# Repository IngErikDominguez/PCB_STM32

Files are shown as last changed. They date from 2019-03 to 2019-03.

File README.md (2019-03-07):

# PCB_STM32
PCB_STM32 

El PCB de Stm32 se comienza con el objetivo de sustituir el arduino nano, por un desarrollo generado aquí. El objetivo del microcontrolador, será embeber la comunicación serial con los dispositivos ccTalk, monitorear sensores que se empiecen a implementar, como lo son: sensor de corriente, voltaje, temperatura y tener una comunicación mas transparente con un software de PC o Raspberry por comunicación serial

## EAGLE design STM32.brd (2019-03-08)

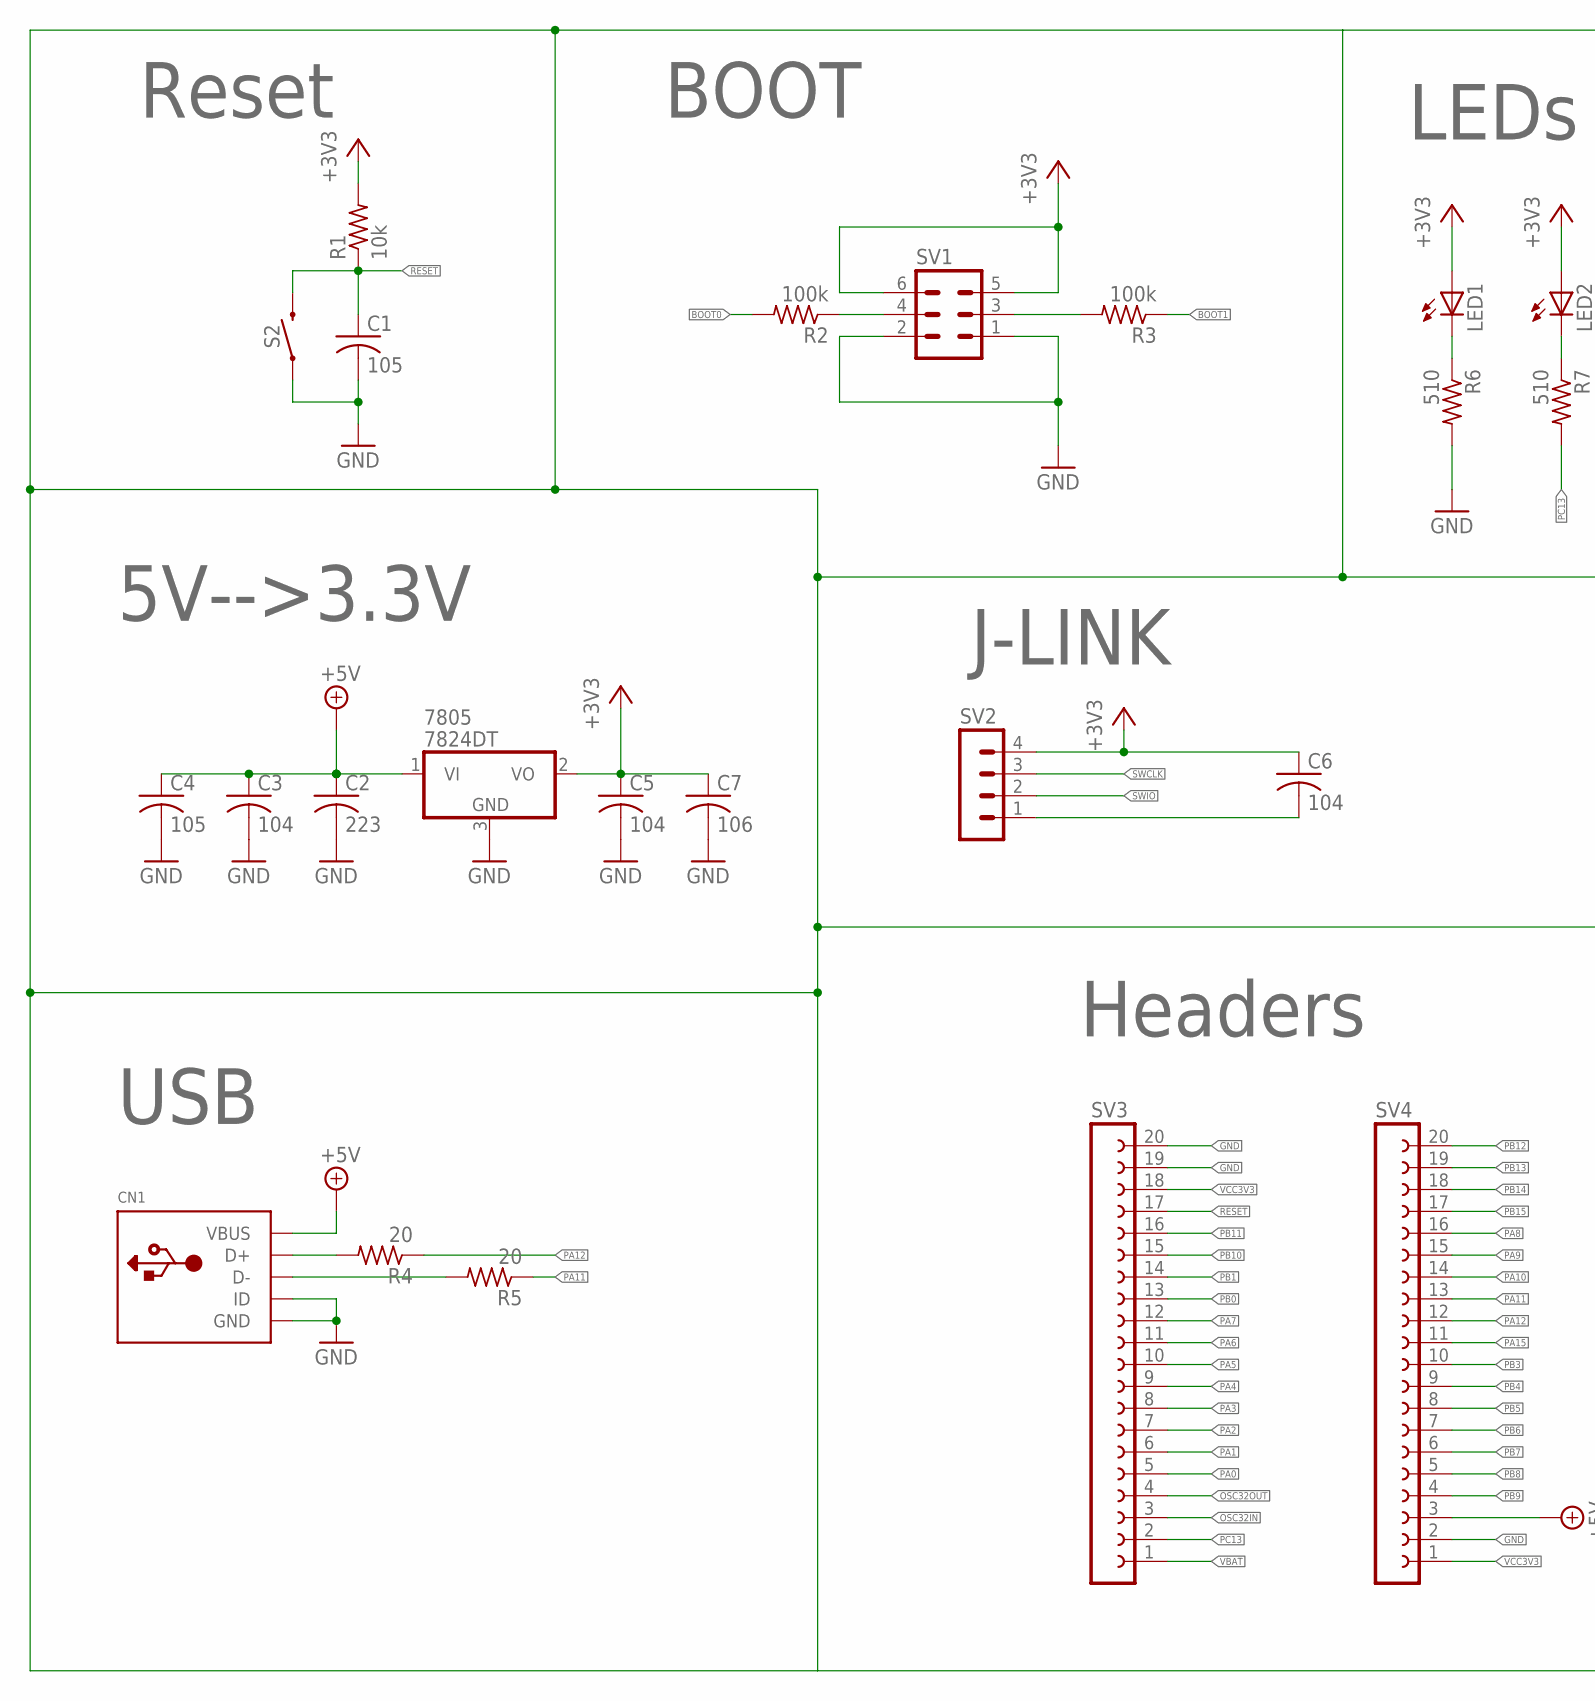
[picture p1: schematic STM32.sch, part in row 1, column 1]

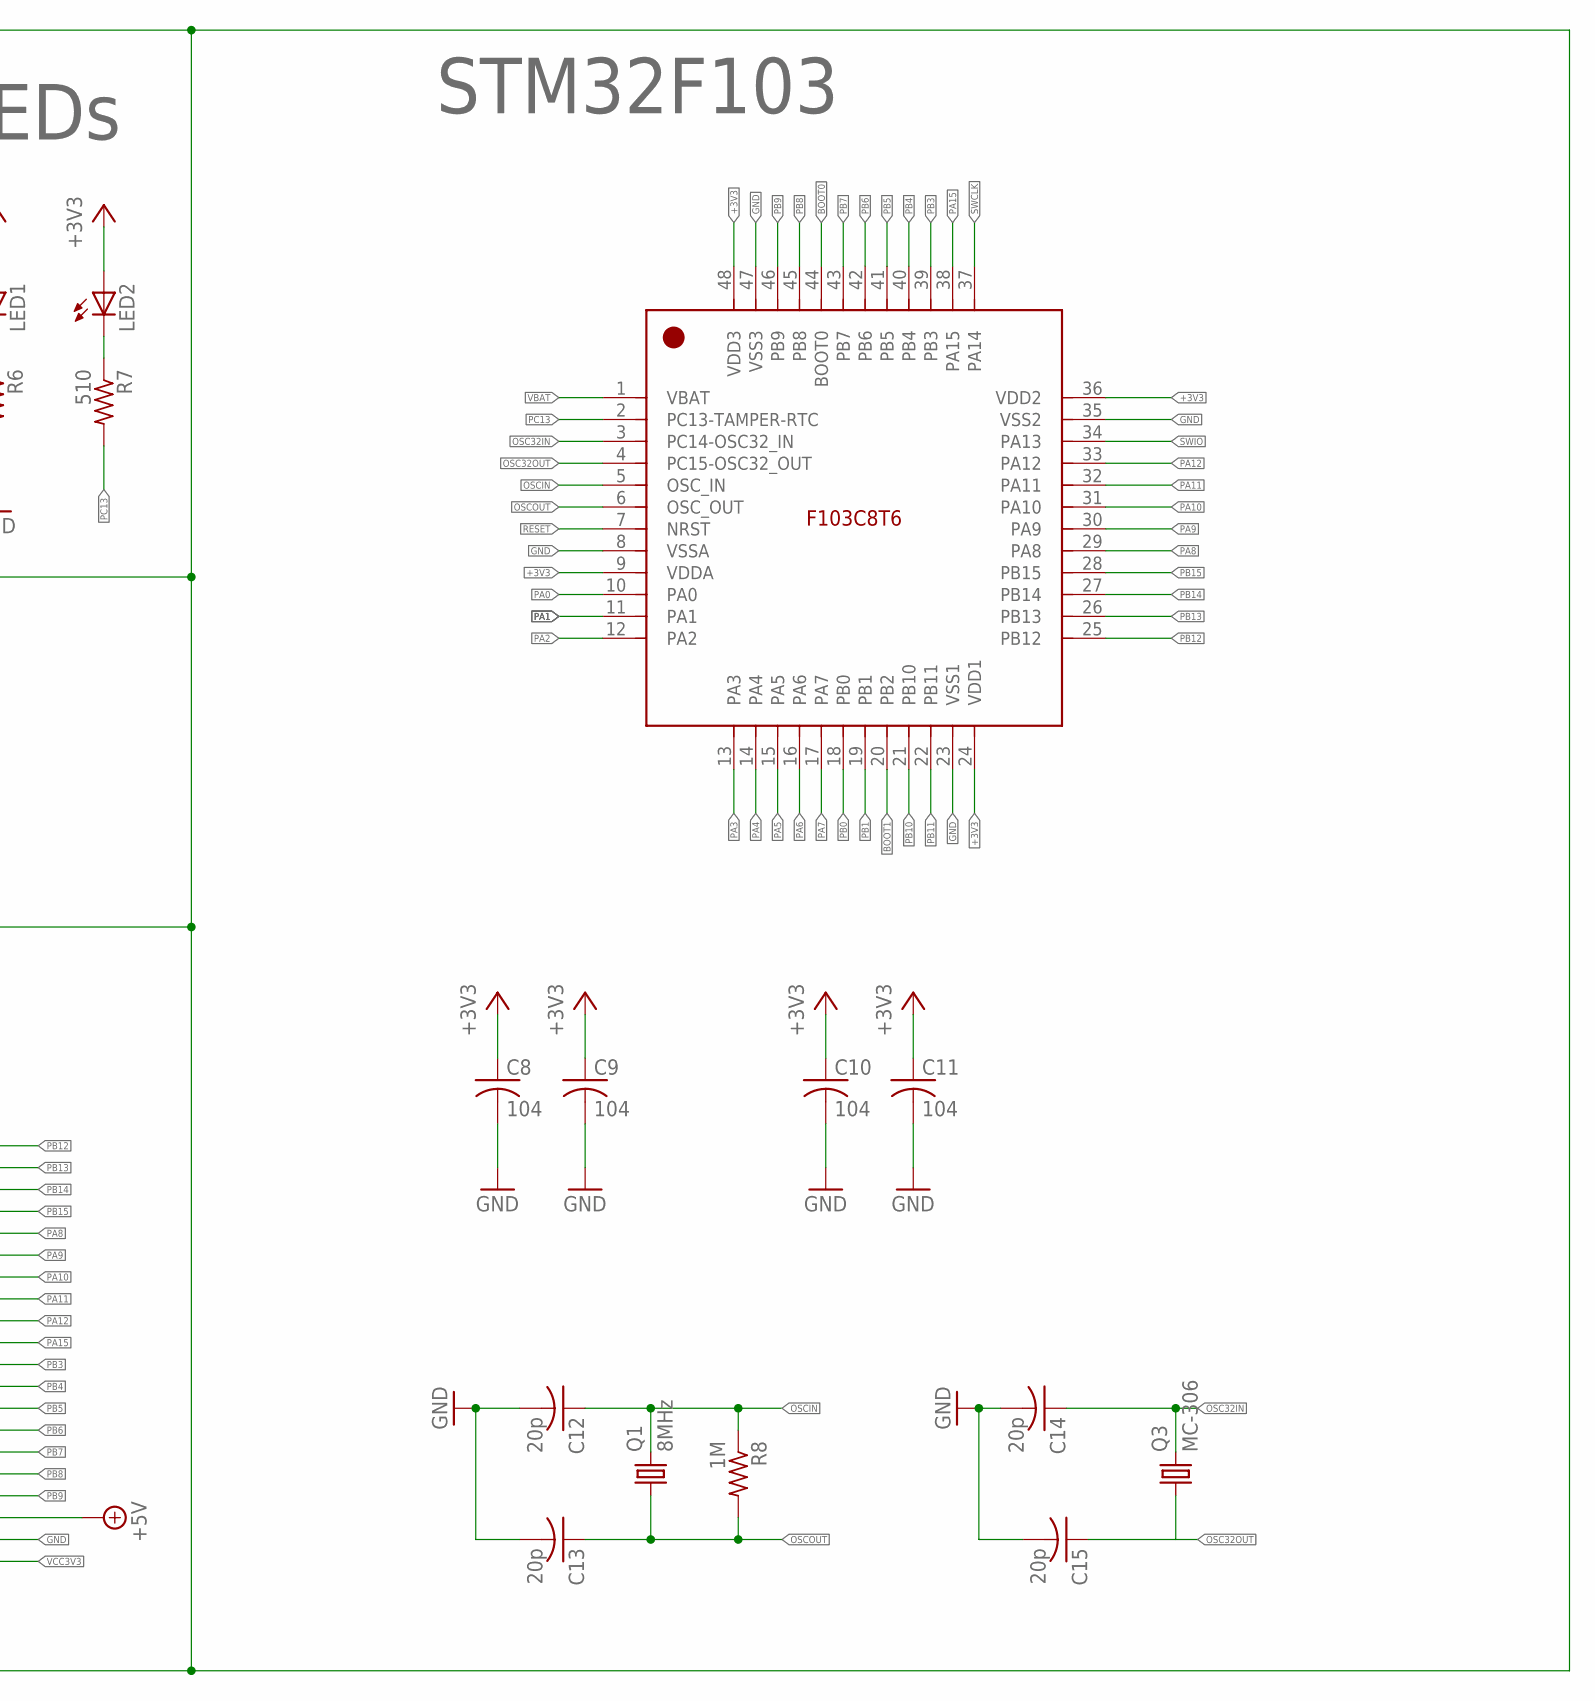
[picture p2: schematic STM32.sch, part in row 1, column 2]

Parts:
7805: 7824DT; TO252
C1: 105; C0603
C2: 223; C0603
C3, C5, C6, C8, C9, C10, C11: 104; C0603
C4: 105; C0805
C7: 106; C0805
C12, C13, C14, C15: 20p; C0603
CN1: USBMINIB; USB-MINIB
LED1, LED2: LEDCHIPLED_0805; CHIPLED_0805
Q1: 8MHz; HC49U70
Q3: MC-306
R1: 10k; R0603
R2, R3: 100k; R0603
R4, R5: 20; R0603
R6, R7: 510; R0603
R8: 1M; R0603
S2: MOMENTARY-SWITCH-SPST-SMD-5.2-REDUNDANT; TACTILE_SWITCH_SMD_5.2MM
SV1: MA03-2
SV2: MA04-1
SV3, SV4: FE20-1; FE20
U$1: STM32F103C8T6; LQFP48_7X7MM_0.5MMPP

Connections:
+3V3: 7805.2 (VO), C5.1, C6.1, C7.1, C8.1, C9.1, C10.1, C11.1, LED1.A, LED2.A, R1.2, SV1.5, SV1.6, SV2.4, U$1.9 (VDDA), U$1.24 (VDD1), U$1.36 (VDD2), U$1.48 (VDD3)
+5V: 7805.1 (VI), C2.1, C3.1, C4.1, CN1.VBUS, SV4.3
BOOT0: R2.2, U$1.44 (BOOT0)
BOOT1: R3.1, U$1.20 (PB2)
GND: 7805.3 (GND), C1.2, C2.2, C3.2, C4.2, C5.2, C7.2, C8.2, C9.2, C10.2, C11.2, C12.2, C13.2, C14.2, C15.2, CN1.GND, CN1.ID, R6.2, S2.1, S2.2 (1), SV1.1, SV1.2, SV3.19, SV3.20, SV4.2, U$1.8 (VSSA), U$1.23 (VSS1), U$1.35 (VSS2), U$1.47 (VSS3)
unnamed: R2.1, SV1.4
unnamed: R3.2, SV1.3
unnamed: LED1.C, R6.1
unnamed: CN1.D+, R4.2
unnamed: CN1.D-, R5.2
unnamed: LED2.C, R7.1
unnamed: C6.2, SV2.1
OSC32IN: C14.1, Q3.4 (2), SV3.3, U$1.3 (PC14-OSC32_IN)
OSC32OUT: C15.1, Q3.1, SV3.4, U$1.4 (PC15-OSC32_OUT)
OSCIN: C12.1, Q1.2, R8.1, U$1.5 (OSC_IN)
OSCOUT: C13.1, Q1.1, R8.2, U$1.6 (OSC_OUT)
PA0: SV3.5, U$1.10 (PA0)
PA1: SV3.6, U$1.11 (PA1)
PA2: SV3.7, U$1.12 (PA2)
PA3: SV3.8, U$1.13 (PA3)
PA4: SV3.9, U$1.14 (PA4)
PA5: SV3.10, U$1.15 (PA5)
PA6: SV3.11, U$1.16 (PA6)
PA7: SV3.12, U$1.17 (PA7)
PA8: SV4.16, U$1.29 (PA8)
PA9: SV4.15, U$1.30 (PA9)
PA10: SV4.14, U$1.31 (PA10)
PA11: R5.1, SV4.13, U$1.32 (PA11)
PA12: R4.1, SV4.12, U$1.33 (PA12)
PA15: SV4.11, U$1.38 (PA15)
PB0: SV3.13, U$1.18 (PB0)
PB1: SV3.14, U$1.19 (PB1)
PB3: SV4.10, U$1.39 (PB3)
PB4: SV4.9, U$1.40 (PB4)
PB5: SV4.8, U$1.41 (PB5)
PB6: SV4.7, U$1.42 (PB6)
PB7: SV4.6, U$1.43 (PB7)
PB8: SV4.5, U$1.45 (PB8)
PB9: SV4.4, U$1.46 (PB9)
PB10: SV3.15, U$1.21 (PB10)
PB11: SV3.16, U$1.22 (PB11)
PB12: SV4.20, U$1.25 (PB12)
PB13: SV4.19, U$1.26 (PB13)
PB14: SV4.18, U$1.27 (PB14)
PB15: SV4.17, U$1.28 (PB15)
PC13: R7.2, SV3.2, U$1.2 (PC13-TAMPER-RTC)
RESET: C1.1, R1.1, S2.3 (2), S2.4 (2), SV3.17, U$1.7 (NRST)
SWCLK: SV2.3, U$1.37 (PA14)
SWIO: SV2.2, U$1.34 (PA13)
VBAT: SV3.1, U$1.1 (VBAT)
VCC3V3: SV3.18, SV4.1

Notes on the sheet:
Reset
BOOT
5V-->3.3V
USB
J-LINK
STM32F103
Headers
LEDs

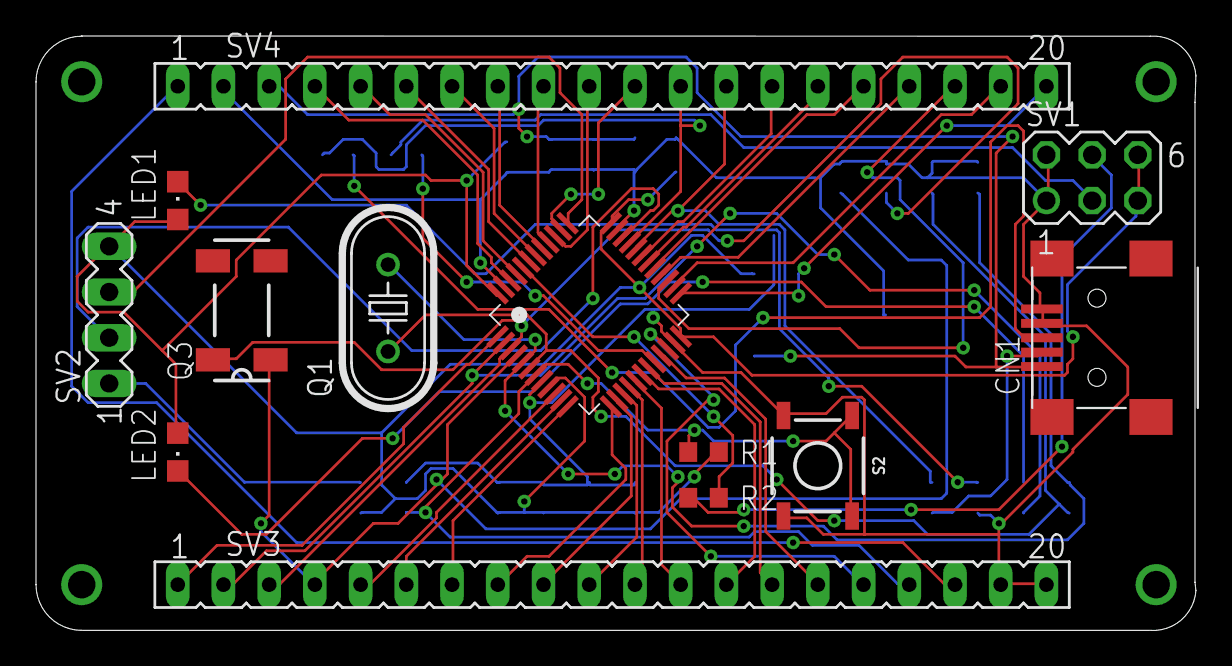
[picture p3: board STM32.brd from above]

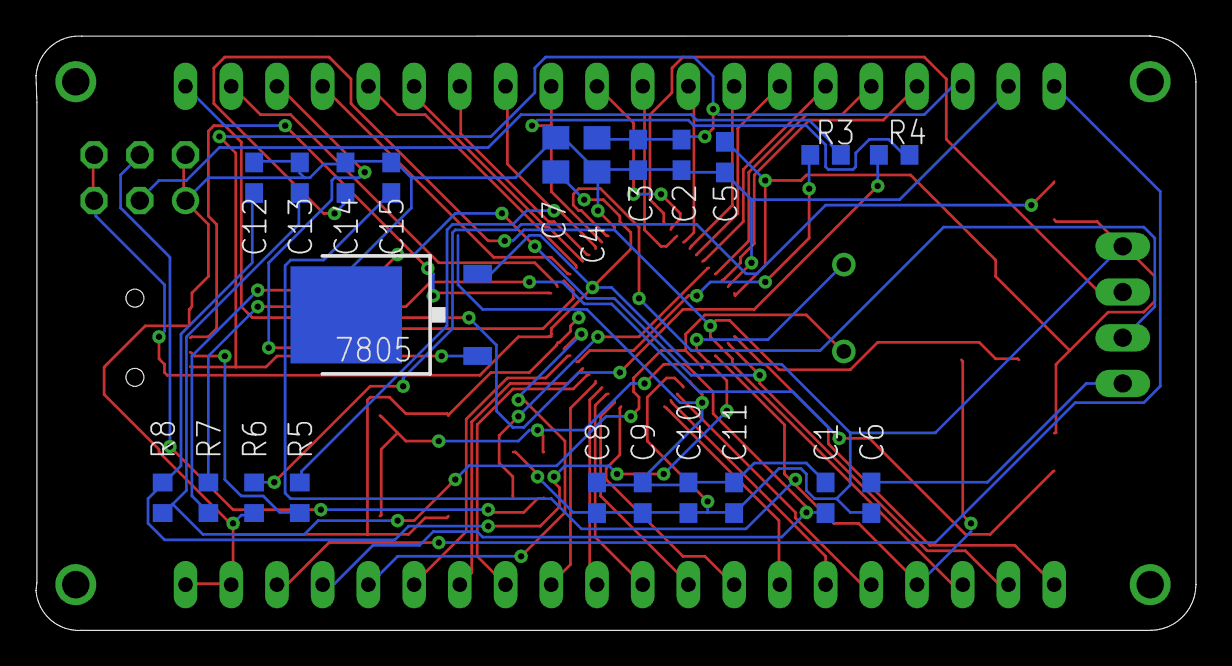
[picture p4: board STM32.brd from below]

Board: 2 copper layers, 64.4 x 33.0 mm, 35 parts (22 on the bottom side), 51 nets.

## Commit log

2019-03-07 V1.0
    Primer esquematico con E/S disponibles para prototipado
    [STM32.brd, STM32.sch]
2019-03-08 V1.0
    Se termina el primer ruteado
    [STM32.brd, STM32.sch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]

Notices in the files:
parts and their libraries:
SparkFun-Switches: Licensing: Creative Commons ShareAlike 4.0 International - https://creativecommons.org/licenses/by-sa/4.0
